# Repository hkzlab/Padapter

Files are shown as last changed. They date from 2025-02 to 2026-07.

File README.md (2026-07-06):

# The Padapter, Genesis/MegaDrive gamepad to C64/Amiga adapter

## DISCLAIMER

Any use of this project is **under your own responsibility**.
You will be responsible of checking the correct construction and functionality of your board.
By using this project You will agree that I cannot be held responsible if it will destroy any of your devices, damage your computer, burn down your house or whatever.

## Introduction

This board converts a SEGA MegaDrive/Genesis 3-button gamepad for C64 (and similar)/Amiga use. It is inspired by the [OpenC64MegaDrivePadAdapter](https://github.com/SukkoPera/OpenC64MegaDrivePadAdapter).

All buttons on the gamepad are demultiplexed and usable by the computer, the adapter also provides two switchable mappings to help with games that used the joystick up direction for jumping.

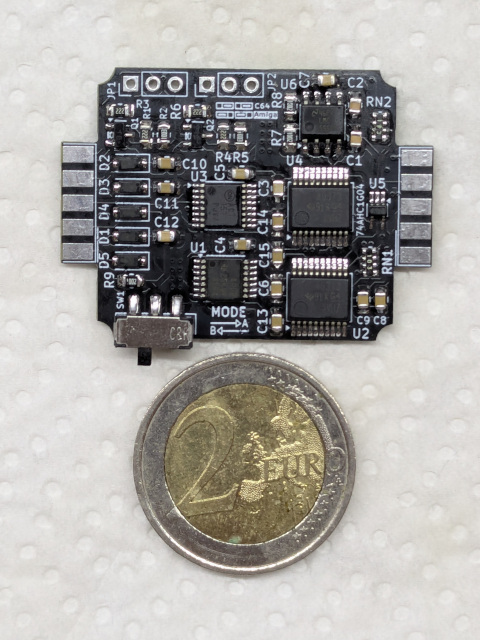
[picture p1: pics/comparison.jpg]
Rev. 1 partially assembled and compared to a 2 EUR coin

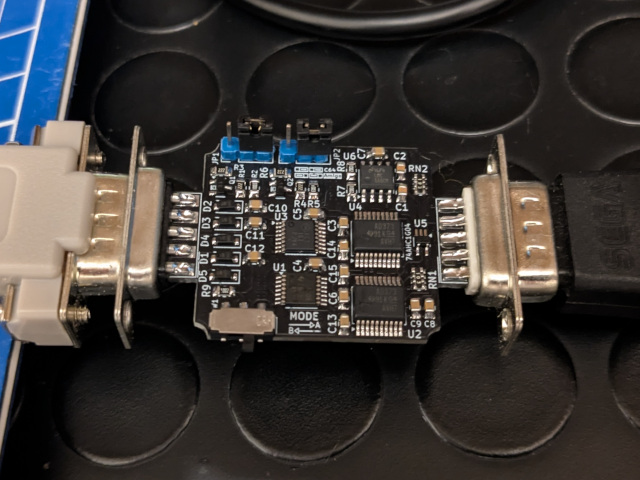
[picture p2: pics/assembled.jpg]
Rev. 1 assembled and connected to a gamepad and an extender


### Ordering the boards

You can order the board for this project at [PCBWay](https://www.pcbway.com/project/shareproject/The_Padapter_6d3f13b7.html) and support me or download 
the gerbers and have them printed wherever you like!!!

Fabrication files are available for both PCBWay and JLCPCB inside the "gerbers" directory. Mind you that I have not yet tested assembly
of this board by either fab, as such you are on your own and you're invited to share your experience and improvements to these files.

## Features

- Small and made with common components
- Maps 3 buttons of the gamepad adapter, allowing their use on both C64 (and similar) and Amiga
- Two switchable button Maps

Amiga and C64 modes can be switched by moving JP1 and JP2:
- Pins 1-2 connected: Amiga Mode
- Pins 2-3 connected: C64 Mode

### Button Maps

Two button maps are available and switchable by flipping SW1 on the board.

They are switchable on the fly.

| | Mode A | Mode B |
| --- | --- | --- |
| START | Button 3 | Button 3 |
| A | Button 3 | Button 2 |
| B | Button 1 | Button 1 |
| C | Button 2 | UP |

## Hardware

The board was designed with [KiCad](https://kicad.org/) EDA.

### Bill of Materials

| Component | Qty | Type / Value | Notes |
| --- | --- | --- | --- |
| C1, C2 |  2  | 10nF/10+V ceramic cap, SMD 0805 | |
| C3 - C15 | 13  | 100nF/10+V ceramic cap, SMD 0805 | |
| D1 - D5 |  5  | 1N4148W SOD-123F diode | |
| J1 |  1  | DSUB-9 Female | Connect toward C64/Amiga, use a connector with solder cups |
| J2 |  1  | DSUB-9 Male | Connect toward MegaDrive pad, use a connector with solder cups |
| JP1, JP2 |  2  | 3 pin 2.54mm headers | Used to select between C64 and Amiga mode |
| Q1, Q2 |  2  | BC847 SOT-23 transistors | |
| R1, R3, R4, R6 |  4  | 2.2K ohm 0805 resistor | |
| R2, R5 |  2  | 100K ohm 0805 resistor | |
| R7 - R9 |  3  | 10K ohm 0805 resistor | |
| RN1, RN2 |  2  | 10K resistor pack, 4x0612 (1206) | |
| SW1 |  1  | SPDT switch, C&K JS102011SAQN | |
| U1 |  1  | 74ACT08 TSSOP-14 | |
| U2, U4 |  2  | 74ACT373 SSOP-20 | |
| U3 |  1  | 74ACT157 TSSOP-16 | |
| U5 |  1  | 74AHC1G04 SOT-353 SC-70 5pin | |
| 555 |  1  | A CMOS 555 counter (e.g. LM555) SOIC-8 | |

### 💰 Selling these boards 💰

I you want to contact me about selling this project, you can reach me via email at `0hkzUNDERSCOREprojects6ATposteoDOTnet` after properly fixing the email address by removing the digits and replacing the uppercase words with the proper characters.

**Contacts via other channels will be ignored**, as it means you did not read this document thoroughly.

"Collaborations" will boil down to the following:

- If you wish to produce and share this project at a loss or at cost, go for it. I am only asking for attribution and to let me know via email.
- If you want to do it for profit, let's discuss it. I'll probably settle for a rough 5% of the profit. Importing components is getting more expensive by the day, so this will contribute to me making future projects available for free.
- I will NOT do customer assistance for you or your customers. This is a hobby, not my job.

If this is not ok for you, you're cordially invited to go bother someone else :)

Authorized sellers will be listed in this README. If you find someone selling my boards without being listed here, it means they're stealing other people's work.

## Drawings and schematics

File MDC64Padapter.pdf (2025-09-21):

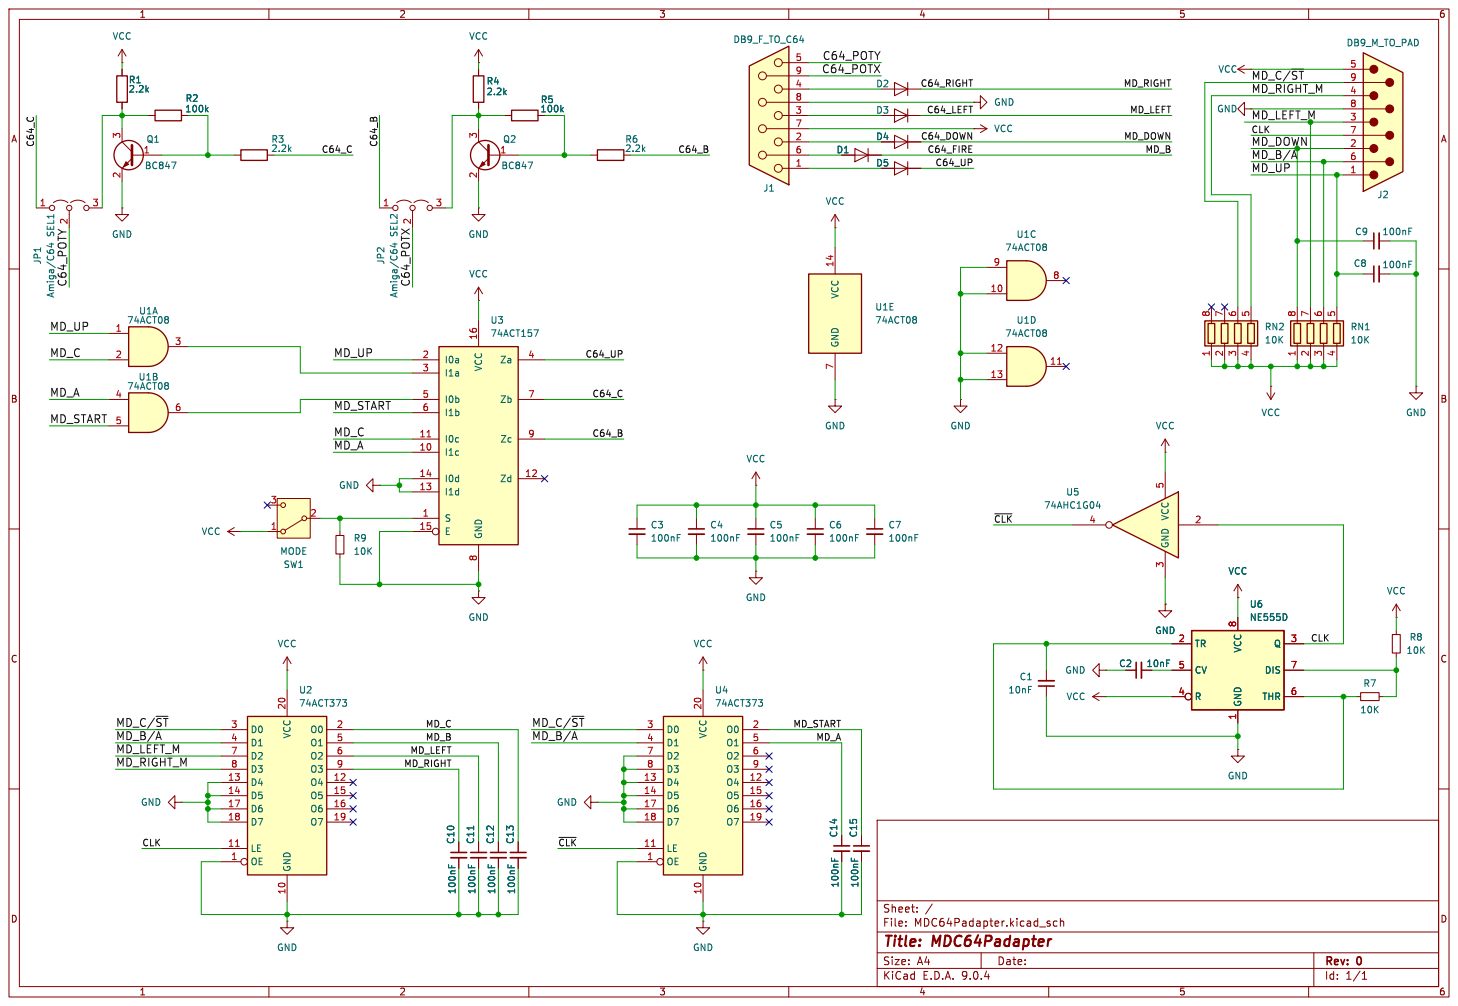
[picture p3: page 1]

Id: 1/1 Title: MDC64Padapter File: MDC64Padapter.kicad_sch Sheet: / VCC 14 GND

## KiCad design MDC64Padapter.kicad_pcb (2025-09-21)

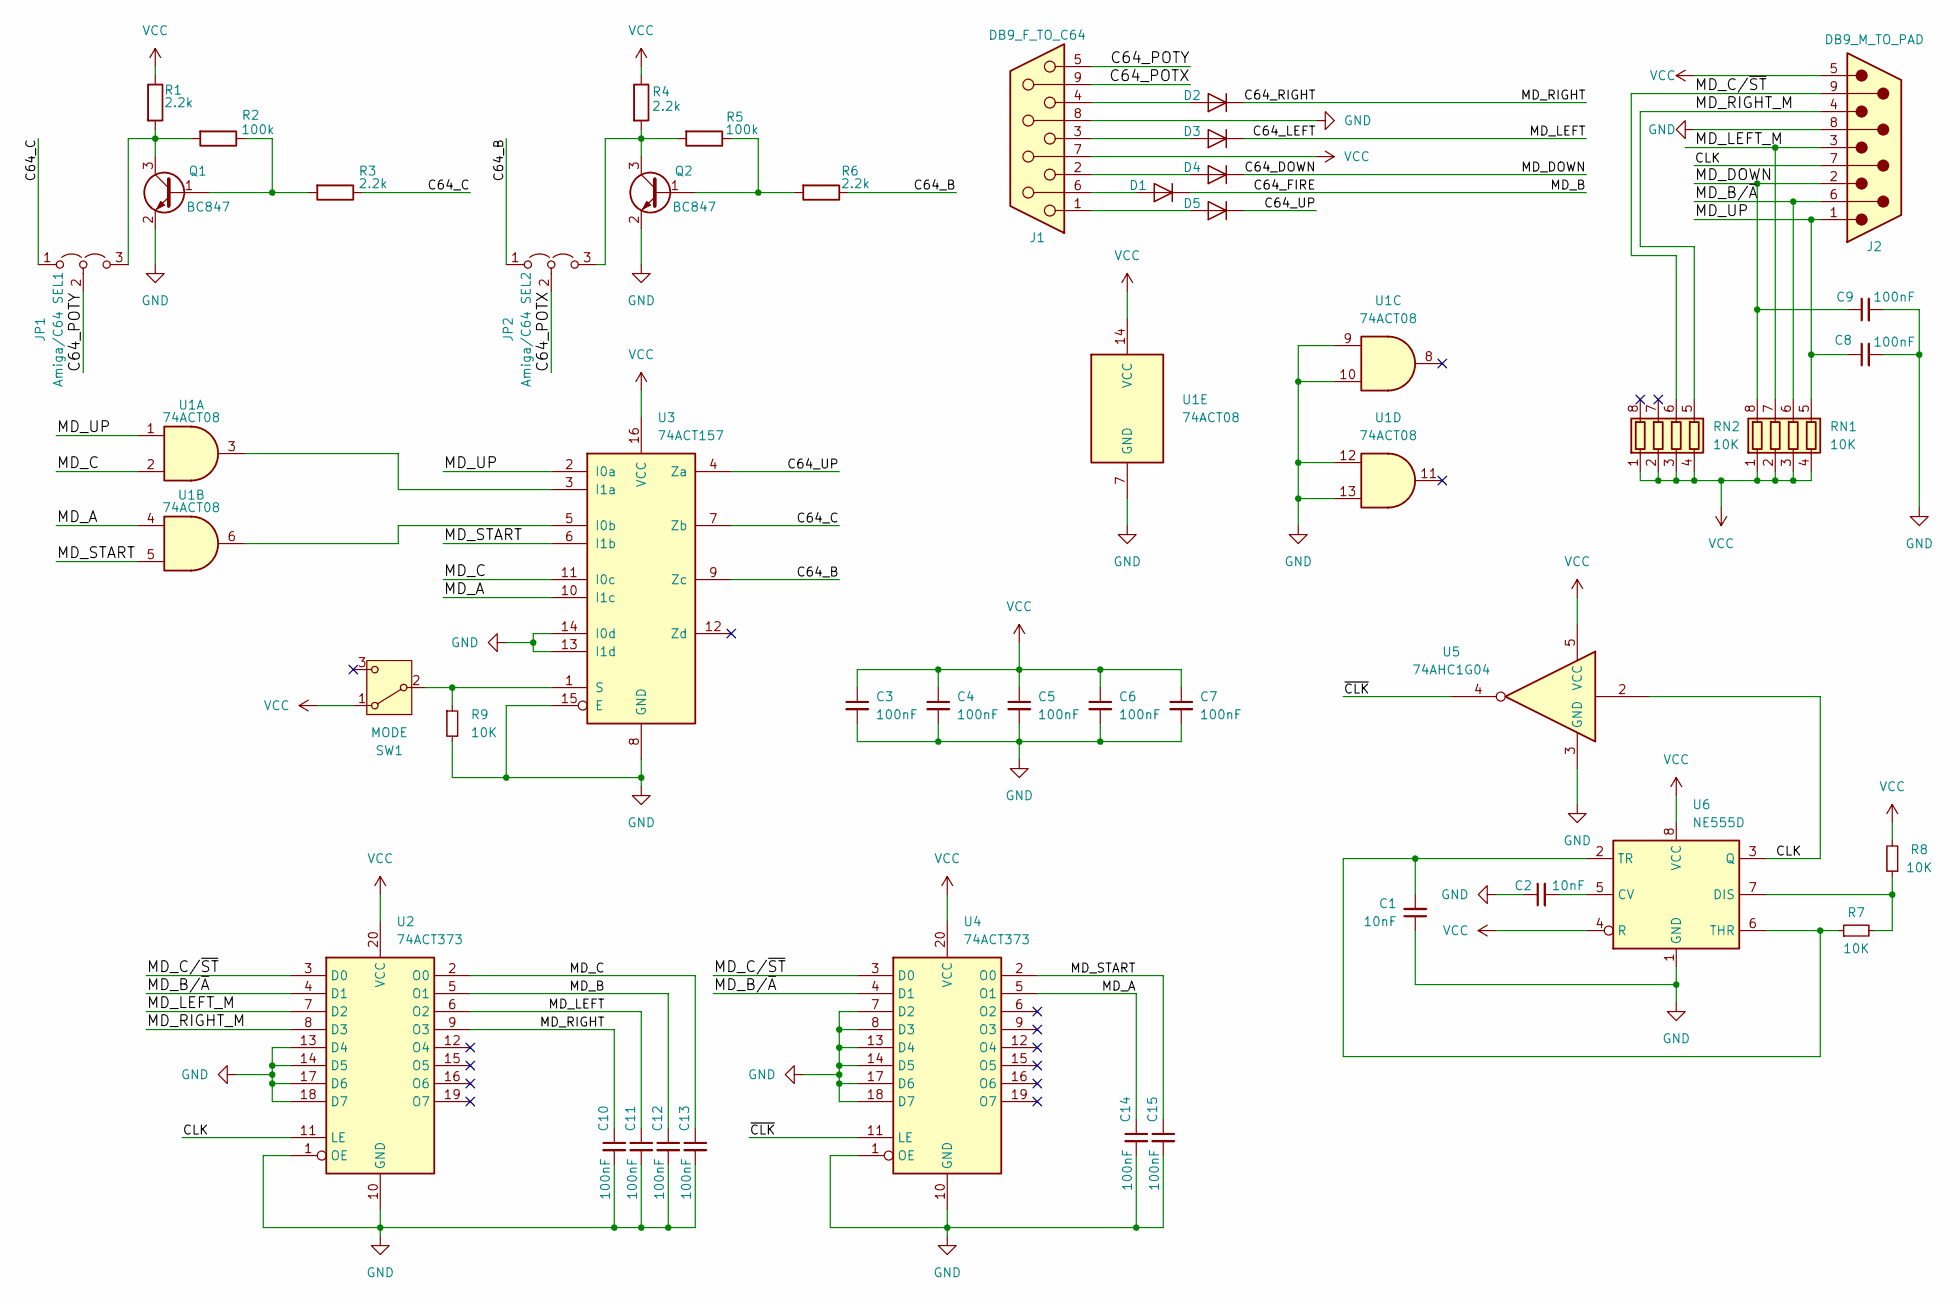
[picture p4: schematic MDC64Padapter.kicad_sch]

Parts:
C1, C2: 10nF; C_0805_2012Metric_Pad1.18x1.45mm_HandSolder; LCSC PN C83170
C3, C4, C5, C6, C7, C8, C9, C10, C11, C12, C13, C14, C15: 100nF; C_0805_2012Metric_Pad1.18x1.45mm_HandSolder; LCSC PN C38141
D1, D2, D3, D4, D5: 1N4148; D_SOD-123F; LCSC PN C83528
J1: DB9_F_TO_C64; DSUB-9_Female_EdgeMount_P2.77mm
J2: DB9_M_TO_PAD; DSUB-9_Male_EdgeMount_P2.77mm
JP1: Amiga/C64 SEL1; PinHeader_1x03_P2.54mm_Vertical
JP2: Amiga/C64 SEL2; PinHeader_1x03_P2.54mm_Vertical
Q1, Q2: BC847; SOT-23; LCSC PN C475630
R1, R3, R4, R6: 2.2k; R_0805_2012Metric_Pad1.20x1.40mm_HandSolder; LCSC PN C17520
R2, R5: 100k; R_0805_2012Metric_Pad1.20x1.40mm_HandSolder; LCSC PN C149504
R7, R8, R9: 10K; R_0805_2012Metric_Pad1.20x1.40mm_HandSolder; LCSC PN C17414
RN1, RN2: 10K; R_Array_Convex_4x0612; LCSC PN C840645
SW1: MODE; SW_SPDT_CK_JS102011SAQN; LCSC PN C221660
U1: 74ACT08; TSSOP-14_4.4x5mm_P0.65mm; LCSC PN C238944
U2, U4: 74ACT373; SSOP-20_5.3x7.2mm_P0.65mm; LCSC PN C4989112
U3: 74ACT157; TSSOP-16_4.4x5mm_P0.65mm; LCSC PN C3239134
U5: 74AHC1G04; SOT-353_SC-70-5_Handsoldering; LCSC PN C148197
U6: NE555D; SOIC-8_3.9x4.9mm_P1.27mm; LCSC PN C41431778

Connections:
/C64_B: JP2.1 (A), R6.1, U3.9 (Zc)
/C64_C: JP1.1 (A), R3.1, U3.7 (Zb)
/C64_DOWN: C9.1, D4.1 (K), J2.2, RN1.8 (R1.2)
/C64_FIRE: C12.1, D1.1 (K), U2.5 (O1)
/C64_LEFT: C11.1, D3.1 (K), U2.6 (O2)
/C64_POTX: J1.9, JP2.2 (C)
/C64_POTY: J1.5, JP1.2 (C)
/C64_RIGHT: C10.1, D2.1 (K), U2.9 (O3)
/C64_UP: D5.1 (K), U3.4 (Za)
/CLK: J2.7, U2.11 (LE), U5.2, U6.3 (Q)
/MD_A: C14.1, U1.4, U3.10 (I1c), U4.5 (O1)
/MD_B/~A: J2.6, RN1.6 (R3.2), U2.4 (D1), U4.4 (D1)
/MD_C: C13.1, U1.2, U2.2 (O0), U3.11 (I0c)
/MD_C/~ST: J2.9, RN2.6 (R3.2), U2.3 (D0), U4.3 (D0)
/MD_LEFT_M: J2.3, RN1.7 (R2.2), U2.7 (D2)
/MD_RIGHT_M: J2.4, RN2.5 (R4.2), U2.8 (D3)
/MD_START: C15.1, U1.5, U3.6 (I1b), U4.2 (O0)
/MD_UP: C8.1, J2.1, RN1.5 (R4.2), U1.1, U3.2 (I0a)
/~CLK: U4.11 (LE), U5.4
GND: C1.1, C2.1, C3.2, C4.2, C5.2, C6.2, C7.2, C8.2, C9.2, C10.2, C11.2, C12.2, C13.2, C14.2, C15.2, J1.8, J2.8, Q1.2 (E), Q2.2 (E), R9.2, U1.7 (GND), U1.9, U1.10, U1.12, U1.13, U2.1 (OE), U2.10 (GND), U2.13 (D4), U2.14 (D5), U2.17 (D6), U2.18 (D7), U3.8 (GND), U3.13 (I1d), U3.14 (I0d), U3.15 (E), U4.1 (OE), U4.7 (D2), U4.8 (D3), U4.10 (GND), U4.13 (D4), U4.14 (D5), U4.17 (D6), U4.18 (D7), U5.3 (GND), U6.1 (GND)
unnamed: D1.2 (A), J1.6
unnamed: D2.2 (A), J1.4
unnamed: D3.2 (A), J1.3
unnamed: D4.2 (A), J1.2
unnamed: D5.2 (A), J1.1
unnamed: JP1.3 (B), Q1.3 (C), R1.2, R2.2
unnamed: JP2.3 (B), Q2.3 (C), R4.2, R5.2
unnamed: Q1.1 (B), R2.1, R3.2
unnamed: Q2.1 (B), R5.1, R6.2
unnamed: R9.1, SW1.2 (B), U3.1 (S)
unnamed: U1.6, U3.5 (I0b)
unnamed: U1.3, U3.3 (I1a)
unnamed: C2.2, U6.5 (CV)
unnamed: R7.2, R8.1, U6.7 (DIS)
unnamed: C1.2, R7.1, U6.2 (TR), U6.6 (THR)
VCC: C3.1, C4.1, C5.1, C6.1, C7.1, J1.7, J2.5, R1.1, R4.1, R8.2, RN1.1 (R1.1), RN1.2 (R2.1), RN1.3 (R3.1), RN1.4 (R4.1), RN2.1 (R1.1), RN2.2 (R2.1), RN2.3 (R3.1), RN2.4 (R4.1), SW1.1 (A), U1.14 (VCC), U2.20 (VCC), U3.16 (VCC), U4.20 (VCC), U5.5 (VCC), U6.4 (R), U6.8 (VCC)

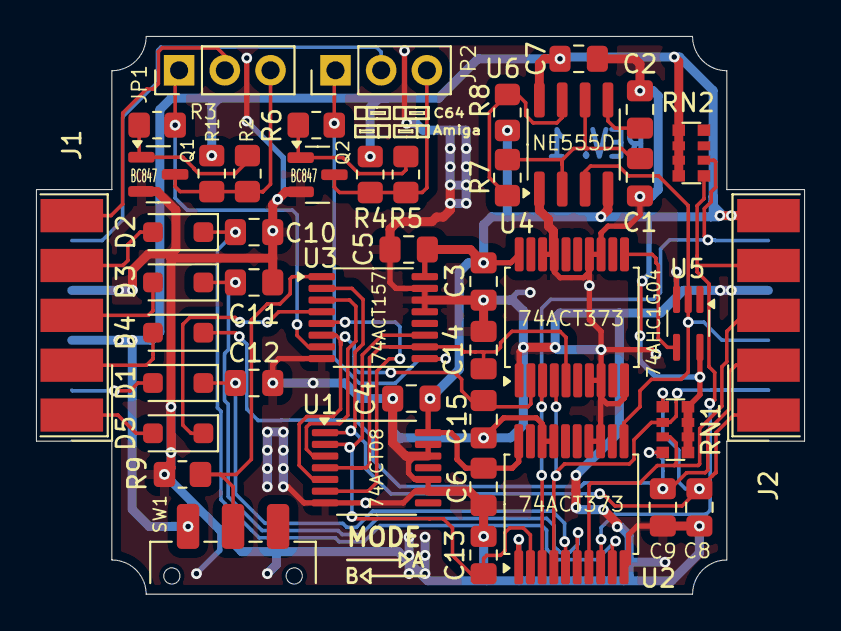
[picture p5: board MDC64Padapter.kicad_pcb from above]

Board: 2 copper layers, 42.7 x 31.0 mm, 44 parts (0 on the bottom side), 36 nets.

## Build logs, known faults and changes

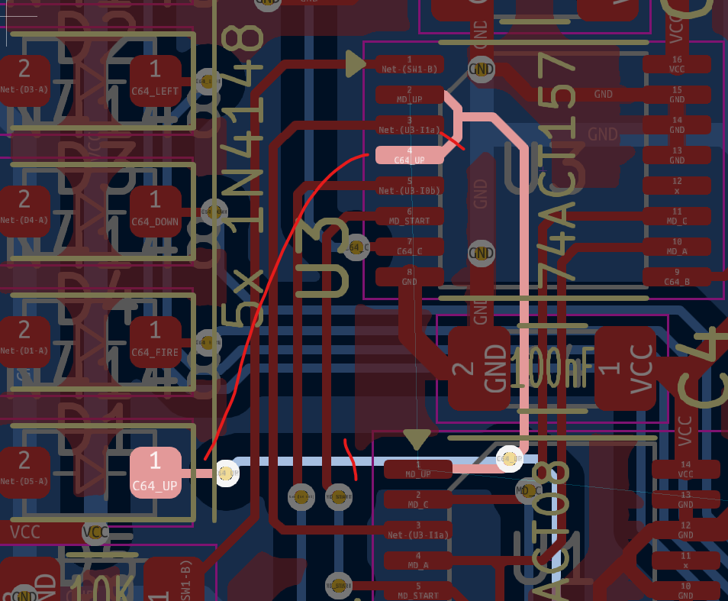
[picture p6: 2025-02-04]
fix/rev_0_fix.png

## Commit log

2025-01-02 First schematic of the padapter
    [MDC64Padapter.kicad_pcb, MDC64Padapter.kicad_sch]
2025-01-02 Use a cmos mux
    [MDC64Padapter.kicad_sch]
2025-01-02 Begin placing components on the PCB
    [MDC64Padapter.kicad_pcb, MDC64Padapter.kicad_sch]
2025-01-02 Reorganize pcb a bit
    [MDC64Padapter.kicad_pcb, MDC64Padapter.kicad_sch]
2025-01-02 First PCB design
    [MDC64Padapter.kicad_pcb, MDC64Padapter.kicad_sch]
2025-01-02 Update adapter
    [MDC64Padapter.kicad_pcb]
2025-01-02 add some silkscreen
    [MDC64Padapter.kicad_pcb]
2025-01-02 Update PCB
    [MDC64Padapter.kicad_pcb]
2025-01-02 Add amiga compatibility
    [MDC64Padapter.kicad_pcb, MDC64Padapter.kicad_sch]
2025-01-02 Tweak some traces
    [MDC64Padapter.kicad_pcb]
2025-01-02 First rev of the board
    [MDC64Padapter.kicad_pcb]
2025-02-03 Change the silkscreen
    [MDC64Padapter.kicad_pcb]
2025-02-04 Fix 555 cap/resistor values
    [MDC64Padapter.kicad_sch]
2025-02-04 Correct connection mistake
    [MDC64Padapter.kicad_sch]
2025-02-05 Fix c64 up signal traces on PCB
    [MDC64Padapter.kicad_pcb]
2025-02-05 Add filter caps on up/down direction
    [MDC64Padapter.kicad_sch]
2025-02-05 Add filter caps for up/down direction
    [MDC64Padapter.kicad_pcb]
2025-02-05 Add filtering caps to the outputs of the latches
    [MDC64Padapter.kicad_sch]
2025-02-05 Begin reorganizing the board
    [MDC64Padapter.kicad_pcb, MDC64Padapter.kicad_sch]
2025-02-05 Reorganize the board a bit
    [MDC64Padapter.kicad_pcb]
2025-02-05 Reroute the adapter
    [MDC64Padapter.kicad_pcb, MDC64Padapter.kicad_sch]
2025-02-05 build rev.1 gerbers
    [MDC64Padapter.kicad_pcb]
2025-02-05 Tweak routing a bit
    [MDC64Padapter.kicad_pcb]
2025-02-13 Tweak schematic
    [MDC64Padapter.kicad_sch]
2025-02-13 Add LCSC PNs
    [MDC64Padapter.kicad_sch]
2025-03-25 Update wrong LCSC numbers for two capacitors
    [MDC64Padapter.kicad_sch]
2025-03-25 Fixed a part number and add fabrication files for PCBWay and JLCPCB
    [MDC64Padapter.kicad_pcb, MDC64Padapter.kicad_sch]
2025-03-25 Add PCBWay link
2025-09-21 Push last changes for rev. 1
    [MDC64Padapter.kicad_pcb, MDC64Padapter.kicad_sch]
